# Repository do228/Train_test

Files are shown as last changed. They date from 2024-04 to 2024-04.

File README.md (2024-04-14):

# 鉄道模型用リポジトリ

内容:
- [コントローラー基盤データ（回路）](controller_board)
- [コントローラー側ファームウェア](server_train)
- [電車側ファームウェア](client_train)

## 使い方

1. [コントローラー基盤データ（回路）](controller_board)を見て部品を集める。
2. コントローラー基盤に部品をはんだ付けで実装する。
3. プログラム上のMACアドレスを変更してコントローラーと電車模型のUUIDが一致するようにしてプログラムを書き込む。

## 必要な部品(コントローラー)

- LM1117GS-3.3(3端子レギュレーター)
- 1uFのコンデンサ
- ボリューム抵抗
- 10~20KΩの抵抗
- 1KΩの抵抗
- DCジャック
- OSL10564という型番の7セグメントLED
- 100Ω~20KΩ抵抗

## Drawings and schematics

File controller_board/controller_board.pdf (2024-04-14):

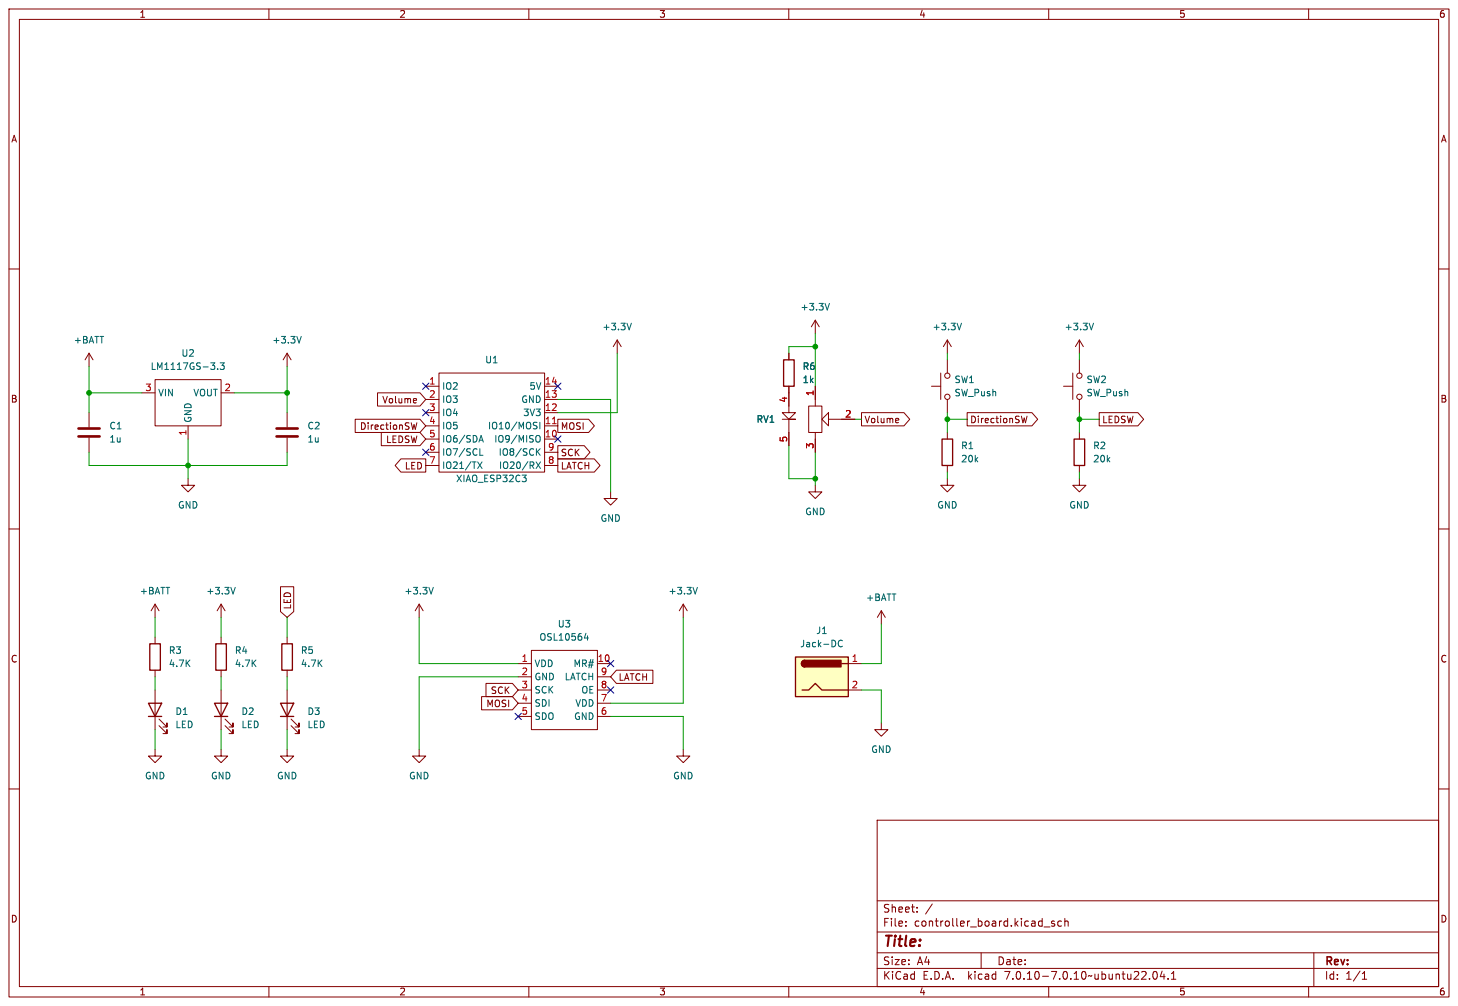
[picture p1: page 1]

Id: 1/1 Title: File: controller_board.kicad_sch Sheet: /

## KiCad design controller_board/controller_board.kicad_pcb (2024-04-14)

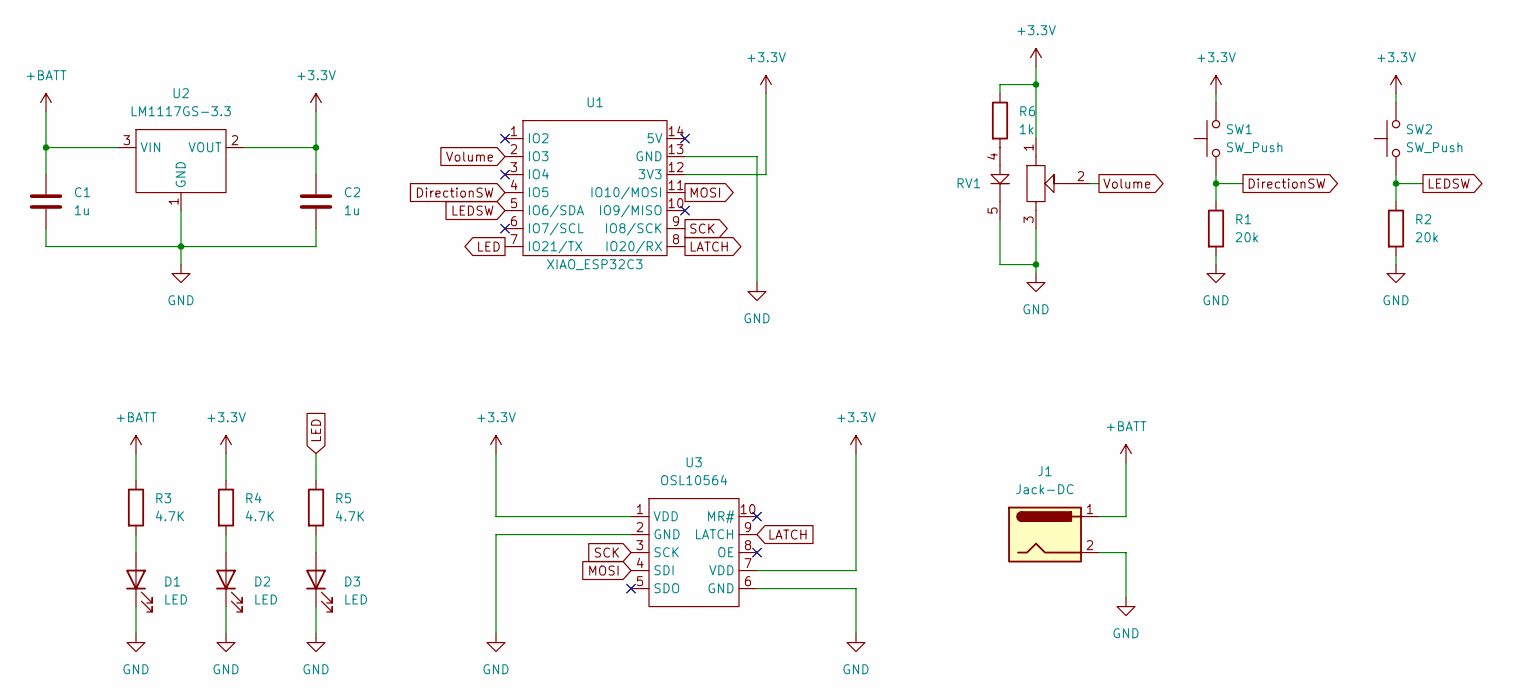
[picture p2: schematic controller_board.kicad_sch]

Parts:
C1, C2: 1u; C_Disc_D5.0mm_W2.5mm_P5.00mm
D1, D2, D3: LED; LED_D3.0mm
J1: Jack-DC; DCJack2.1
R1, R2: 20k; R_Axial_DIN0204_L3.6mm_D1.6mm_P7.62mm_Horizontal
R3, R4, R5: 4.7K; R_Axial_DIN0204_L3.6mm_D1.6mm_P7.62mm_Horizontal
R6: 1k; R_Axial_DIN0204_L3.6mm_D1.6mm_P7.62mm_Horizontal
RV1: VR-sliderV2
SW1, SW2: SW_Push; PinHeader_1x02_P2.54mm_Vertical
U1: XIAO_ESP32C3
U2: LM1117GS-3.3; SOT-223-3_TabPin2
U3: OSL10564; OSL10564-MODULE

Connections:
+3.3V: C2.1, R4.1, R6.1, RV1.1, SW1.2, SW2.2, U1.12 (3V3), U2.2 (VOUT), U3.1 (VDD), U3.7 (VDD)
+BATT: C1.1, J1.1, R3.1, U2.3 (VIN)
DirectionSW: R1.1, SW1.1, U1.4 (IO5)
GND: C1.2, C2.2, D1.1 (K), D2.1 (K), D3.1 (K), J1.2, R1.2, R2.2, RV1.3, RV1.5, U1.13 (GND), U2.1 (GND), U3.2 (GND), U3.6 (GND)
LATCH: U1.8 (IO20/RX), U3.9 (LATCH)
LED: R5.1, U1.7 (IO21/TX)
LEDSW: R2.1, SW2.1, U1.5 (IO6/SDA)
MOSI: U1.11 (IO10/MOSI), U3.4 (SDI)
unnamed: D1.2 (A), R3.2
unnamed: D2.2 (A), R4.2
unnamed: D3.2 (A), R5.2
unnamed: R6.2, RV1.4
SCK: U1.9 (IO8/SCK), U3.3 (SCK)
Volume: RV1.2, U1.2 (IO3)

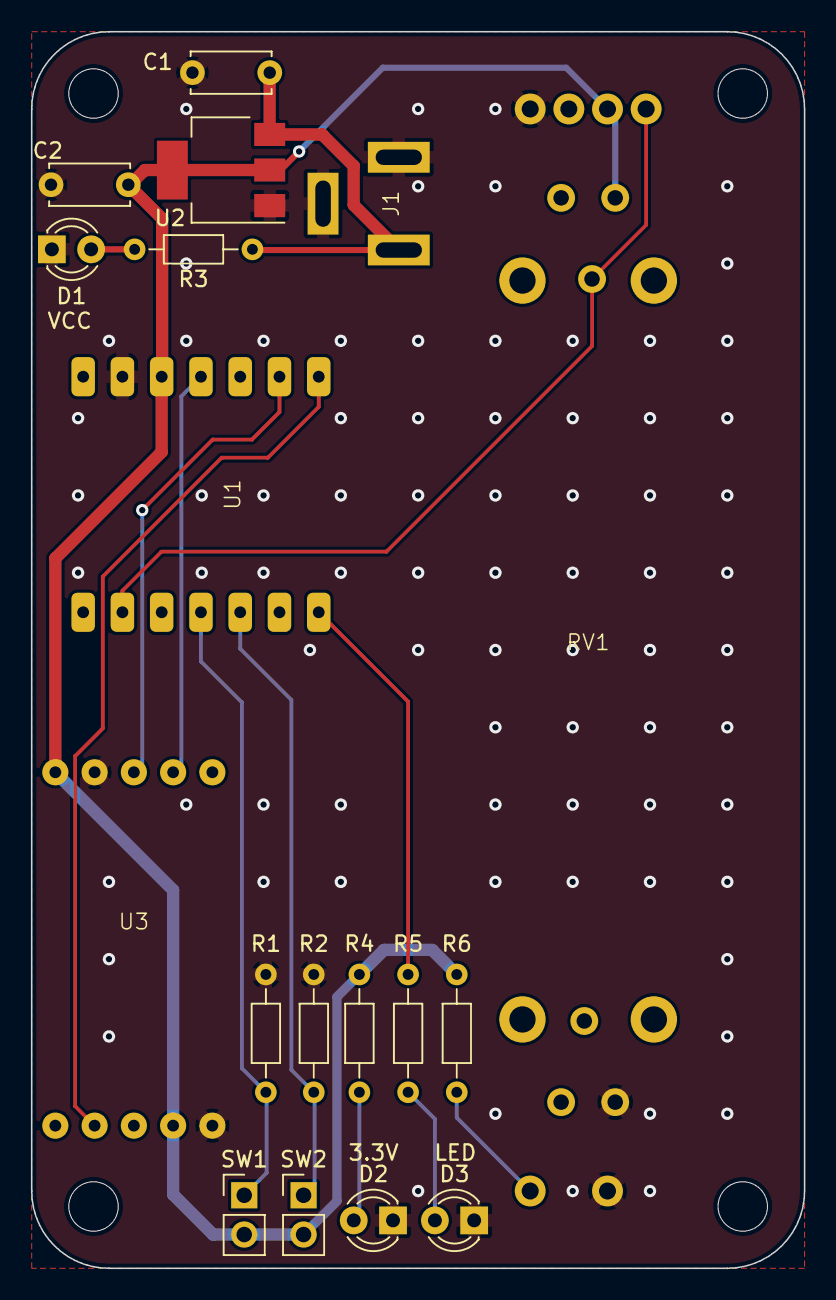
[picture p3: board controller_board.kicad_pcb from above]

Board: 2 copper layers, 50.0 x 80.0 mm, 18 parts (0 on the bottom side), 14 nets.

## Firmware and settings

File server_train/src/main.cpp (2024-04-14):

#include <Arduino.h>
#include <TrainController.hpp>
// 7segment
#include <SevenSegmentLEDDriver.hpp>

/////////////////////////　グローバル変数の宣言　/////////////////////////

#define DEVICE_NAME "server1"                                        // ここでサーバーの名前を決める。
BLEUUID SERVICE_UUID("3fd19879-3490-470c-b26d-28dce8c1dd83");        // サービスのUUIDを指定。
BLEUUID CHARACTERISTIC_UUID("5da663e5-1dd1-4080-930f-915988c9a282"); // キャラクタリスティックのUUIDを指定。
// 2機 3842a4a8-c709-457f-941f-df937f30fc6c
// 2機 9faf8474-2648-4935-b05c-f7e0356e9035
// 3機 0789b10d-cd5c-49f6-8583-7857f06fe548
// 3機 9c78e978-5856-46ee-b48b-231662dd27d8
// 4機 a22c7f7d-1de6-4649-9f5a-548b944b4ca3
// 4機 f4d2cd27-988d-4ed7-8f5c-ca8a4d214eb1

#define LED_pin 6       // LEDの接続PIN
#define direction_pin 5 // 方向切り替えスイッチの接続PIN
#define VOLUME 3        // ボリュームの接続PIN

uint8_t velocity = 0; // 0 ~ 255で速度
bool direction = 0;   // 1:前進
bool LED_status = 0;  // 1:LEDを点灯

// 7segment
SevenSegmentLEDDriver SevenSegDriver;

///////////////////////// ここまで ///////////////////////

void setup()
{
  ///////////////////////////　Bluetoothをつなぐ前に一度だけ行う処理を書く(編集可) //////////////////////////////////
  // 7Segment
  SevenSegDriver.init();         // 7segmentの初期化
  Serial.begin(115200);          // シリアル通信の開始
  pinMode(VOLUME, INPUT);        // ボリュームの接続PINを入力に設定
  pinMode(LED_pin, INPUT);       // LEDの接続PINを入力に設定
  pinMode(direction_pin, INPUT); // 方向切り替えスイッチの接続PINを入力に設定

  ////////////////////////////　ここまで　////////////////////////////////////

  doInitialize(DEVICE_NAME, SERVICE_UUID, CHARACTERISTIC_UUID); // BLEの初期化
  //////////////////////  Blutooth接続中に一度だけ行う処理(編集可) ////////////////////////////
  Serial.println("connecting to client"); // シリアル通信でconnecting to clientと表示

  //////////////////////　ここまで //////////////////////////////
}

void loop()
{
  if (device_connected && !abnormal) // 接続されているかつ異常がないか
  {
    if (bReadyTicker) // タイマーが準備できているか
    {
      ///////////////////////////　ここから繰り返し行う処理を書く(編集可)　//////////////////////////////

      // スイッチの状態を読む、LEDのon/off
      if (digitalRead(LED_pin))
      {
        long LED_gage = 0;
        while (digitalRead(LED_pin))
        {
          LED_gage++;
        }
        // ゲージが溜まっているか
        if (LED_gage > 100000)
        {
          // 状態を反転する
          if (LED_status)
          {
            LED_status = 0;
          }
          else
          {
            LED_status = 1;
          }
          delay(50); // チャタリング防止
        }
      }

      // スイッチの状態を読む、進行方向
      if (digitalRead(direction_pin))
      {
        long direction_gage = 0;
        while (digitalRead(direction_pin))
        {
          direction_gage++;
        }
        // ゲージが溜まっているか
        if (direction_gage > 100000)
        {
          // 状態を反転する
          if (direction)
          {
            direction = 0;
          }
          else
          {
            direction = 1;
          }
          delay(50); // チャタリング防止
        }
      }

      velocity = analogRead(VOLUME) * 255 / 4095; // ボリュームの値を読み取る
      if (velocity >= 256)                        // 256以上なら
      {
        velocity = 255; // 255にする
      }
      // 7segment
      SevenSegDriver.ShowDigits((uint8_t)velocity * 9 / 255);                         // 7segmentに速度を表示
      Serial.printf("v : %d, dir : %d, LED : %d\n", velocity, direction, LED_status); // 速度、方向、LEDの状態を表示
      sendData(velocity, direction, LED_status);                                      // 速度、方向、LEDの状態を送信
      ///////////////////////////  ここまで  //////////////////////////////
    }
  }
}

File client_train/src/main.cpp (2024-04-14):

#include <Arduino.h>
#include <TrainMD.hpp>

#define LED_forward 8  // 前進時LEDの接続PIN
#define LED_backward 7 // 後進時LEDの接続PIN
#define LED_always 6   // 常時点灯LEDの接続PIN
#define IN1 10         // モータードライバーのIN1
#define IN2 9          // モータードライバーのIN2

BLEUUID SERVICE_UUID("3fd19879-3490-470c-b26d-28dce8c1dd83");        // サービスのUUIDを指定。
BLEUUID CHARACTERISTIC_UUID("5da663e5-1dd1-4080-930f-915988c9a282"); // キャラクタリスティックのUUIDを指定。
// 2機 3842a4a8-c709-457f-941f-df937f30fc6c
// 2機 9faf8474-2648-4935-b05c-f7e0356e9035
// 3機 0789b10d-cd5c-49f6-8583-7857f06fe548
// 3機 9c78e978-5856-46ee-b48b-231662dd27d8
// 4機 a22c7f7d-1de6-4649-9f5a-548b944b4ca3
// 4機 f4d2cd27-988d-4ed7-8f5c-ca8a4d214eb1

void setup()
{
  Serial.begin(115200);               //  シリアル通信の開始
  Serial.println("Hello I'm client"); //  シリアル通信でHello I'm clientと表示
  //////////////////////////////　開始時一度だけ行われる処理(編集可) /////////////////////////

  pinMode(LED_forward, OUTPUT);  // LEDの接続PINを出力に設定
  pinMode(LED_backward, OUTPUT); // LEDの接続PINを出力に設定
  pinMode(LED_always, OUTPUT);   // LEDの接続PINを出力に設定

  ledcSetup(1, 2000, 8); // PWMの設定
  ledcAttachPin(IN1, 1); // ピンの設定

  ledcSetup(2, 2000, 8); // PWMの設定
  ledcAttachPin(IN2, 2); // ピンの設定

  //////////////////////////////　ここまで　////////////////////////////
  if (doInitialize(SERVICE_UUID, CHARACTERISTIC_UUID)) //  BLEの初期化
  {
    Serial.println("Connected to the TrainController"); //  シリアル通信でConnected to the TrainControllerと表示
  }
}

void loop()
{
  // 接続状態なら
  if (deviceConnected)
  {
    // 値が更新されていれば
    if (enableNewData)
    {
      ///////////////////////////////////////　受信が行われたあと行う処理(編集可)　///////////////////////////////////
      Serial.printf("velocity : %d\n", data.velocity);   // 速度を表示
      Serial.printf("direction: %d\n", data.direction);  // 方向を表示
      Serial.printf("LED      : %d\n", data.LED_status); // LEDの状態を表示

#if 0
      if(data.direction = 1){
      digitalWrite(LED_forward,data.LED_status);
      digitalWrite(LED_backward,LOW);
      digitalWrite(LED_always,HIGH);
      ledcWrite(1,data.velocity);
      Serial.printf("A \n");
      }
      if(data.direction = 0){
      digitalWrite(LED_forward,LOW);
      digitalWrite(LED_backward,data.LED_status);
      digitalWrite(LED_always,HIGH);
      ledcWrite(2,data.velocity);
      Serial.printf("B \n");
      }
      else{
      digitalWrite(LED_forward,LOW);
      digitalWrite(LED_backward,LOW);
      digitalWrite(LED_always,LOW);
      ledcWrite(2,0);
      Serial.printf("C \n");
      }
#endif

#if 1
      if (data.direction) // 方向が1なら
      {
        ledcWrite(1, data.velocity); // PWMの値を設定
        ledcWrite(2, 0);             // PWMの値を設定
        Serial.println("Forword");   // シリアル通信でForwordと表示
      }
      else // 方向が0なら
      {
        ledcWrite(2, data.velocity); // PWMの値を設定
        ledcWrite(1, 0);             // PWMの値を設定
        Serial.println("Backword");  // シリアル通信でBackwordと表示
      }

      if (data.LED_status) // LEDの状態が1なら
      {
        if (data.direction) // 方向が1なら
        {
          digitalWrite(LED_forward, HIGH); // 前照灯を点灯
          digitalWrite(LED_backward, LOW); // 後照灯を消灯
          digitalWrite(LED_always, HIGH);  // 常時点灯LEDを点灯
        }
        else // 方向が0なら
        {
          digitalWrite(LED_forward, LOW);   // 前照灯を消灯
          digitalWrite(LED_backward, HIGH); // 後照灯を点灯
          digitalWrite(LED_always, HIGH);   // 常時点灯LEDを点灯
        }
      }
      else // LEDの状態が0なら
      {
        digitalWrite(LED_forward, LOW);  // 前照灯を消灯
        digitalWrite(LED_backward, LOW); // 後照灯を消灯
        digitalWrite(LED_always, LOW);   // 常時点灯LEDを消灯
      }
#endif

      /////////////////////////////////////// ここまで ////////////////////////////////////////////

      enableNewData = false;
    }
    // 接続状態でなければ、再接続する。
  }
  else if (doScan) // スキャン指示があれば
  {
    BLEDevice::getScan()->start(0); // スキャンを開始する
  }
}

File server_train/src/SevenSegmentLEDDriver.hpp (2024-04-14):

/**
 * @file SevenSegmentLEDDriver.hpp
 * @author GN10
 * @brief 7セグメントLEDドライバーのクラス
 * @version 0.1
 * @date 2024-04-15
 *
 * @copyright Copyright (c) 2024
 *
 */
#include <Arduino.h>
#include <SPI.h>

class SevenSegmentLEDDriver
{
private:
    static const uint8_t sck = 8;    // 7segmentのSCK
    static const uint8_t latch = 20; // 7segmentのRCK
    static const uint8_t sdi = 10;   // 7segmentのDIN
    const byte digits[10] = {
        0b11111100, // 0
        0b01100000, // 1
        0b11011010, // 2
        0b11110010, // 3
        0b01100110, // 4
        0b10110110, // 5
        0b10111110, // 6
        0b11100000, // 7
        0b11111110, // 8
        0b11110110, // 9
    };

public:
    void init()
    {
        pinMode(latch, OUTPUT);    // 7segmentのRCKを出力に設定
        pinMode(sck, OUTPUT);      // 7segmentのSCKを出力に設定
        pinMode(sdi, OUTPUT);      // 7segmentのDINを出力に設定
        SPI.begin();               // SPI通信の開始
        SPI.setBitOrder(LSBFIRST); // ビットの順番を設定
        SPI.setDataMode(0);        // データモードを設定
    }
    /**
     * @brief 7セグメントLEDに数字を表示する
     *
     * @param number 表示する数字
     */
    void ShowDigits(uint8_t number)
    {
        try
        {
            digitalWrite(latch, LOW);     // 7segmentのRCKをLOWにする
            SPI.transfer(digits[number]); // 7segmentに数字を表示
            digitalWrite(latch, HIGH);    // 7segmentのRCKをHIGHにする
        }
        catch (const std::exception &e) // 例外処理
        {
        }
    }
    /**
     * @brief 7セグメントLEDにセグメントを表示する
     *
     * @param segment 表示するセグメント
     */
    void ShowSegment(byte segment)
    {
        digitalWrite(latch, LOW);
        SPI.transfer((byte)segment);
        digitalWrite(latch, HIGH);
    }
};

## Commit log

2023-09-29 UUIDのバリエーションを追加。7セグのプログラムの完成
2024-04-14 README追加
2024-04-14 自動整形
2024-04-14 コメント追加
2024-04-14 READMEのfix
2024-04-14 必要なものリスト追加
